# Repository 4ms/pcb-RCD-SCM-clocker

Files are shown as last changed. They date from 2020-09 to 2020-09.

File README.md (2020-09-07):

# PCB for RCD and SCM eurorack modules #

## Rotating Clock Divider, and Shuffling Clock Multiplier ##

### Pre-built versions (PCB v1.2) and Kit version (PCB v1.0.x) ###

This repository is an archive for the kit and pre-built versions of the RCD and SCM.

While we believe these files are accurate, there may be minor variations and/or corrections made during assembly that aren't recorded in these files.

Copyright (c) 2010, 2011, 2014, 2020 Dan Green (danngreen1@gmail.com)

Licensed by the [CC BY-NC-SA license](https://creativecommons.org/licenses/by-nc-sa/4.0/) (Creative Commons, Attribution, NonCommercial, ShareAlike).

Please read the above license carefully and contact us if you have any questions regarding acceptable use of these files.

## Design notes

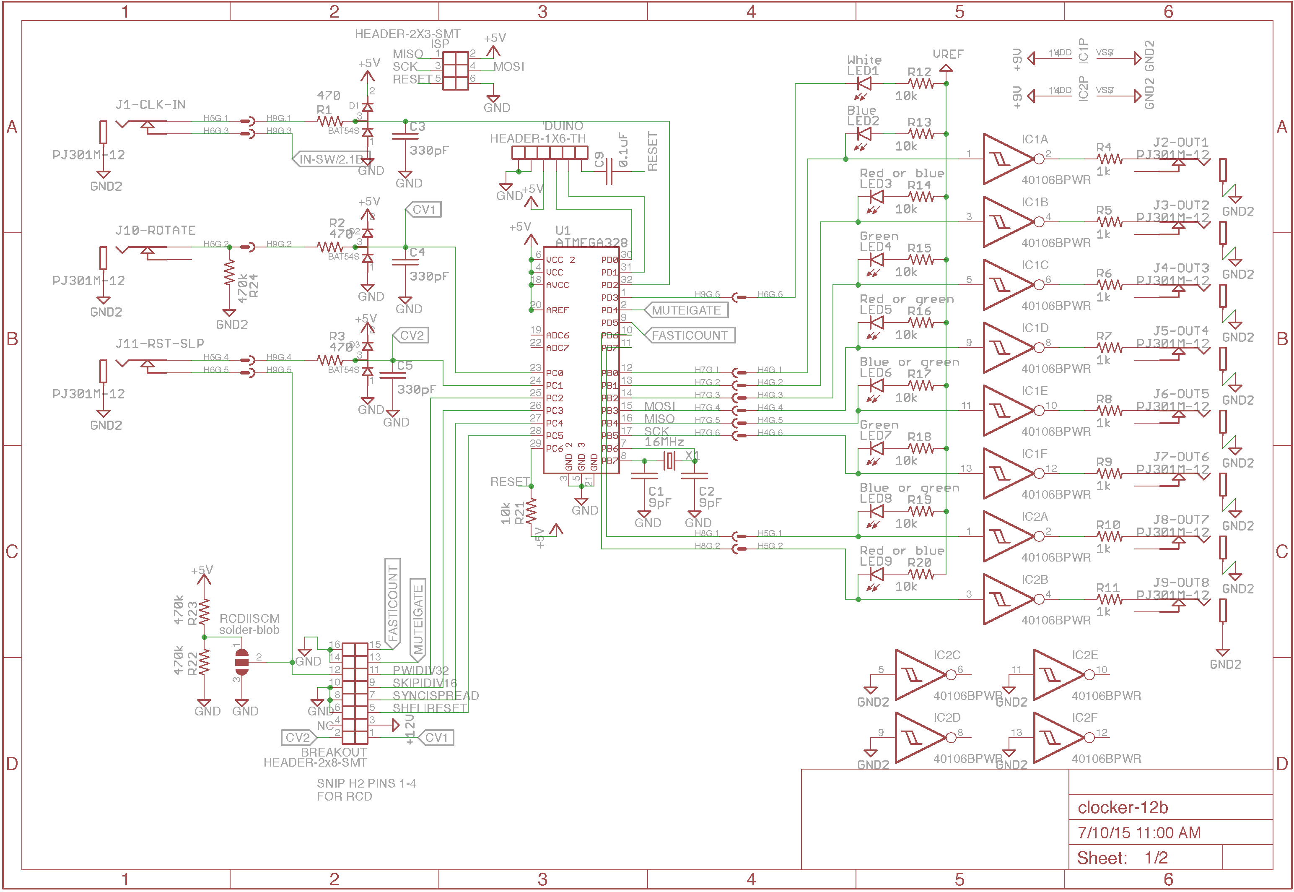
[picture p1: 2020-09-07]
pcb-v1.2/clocker-schematic-1.png

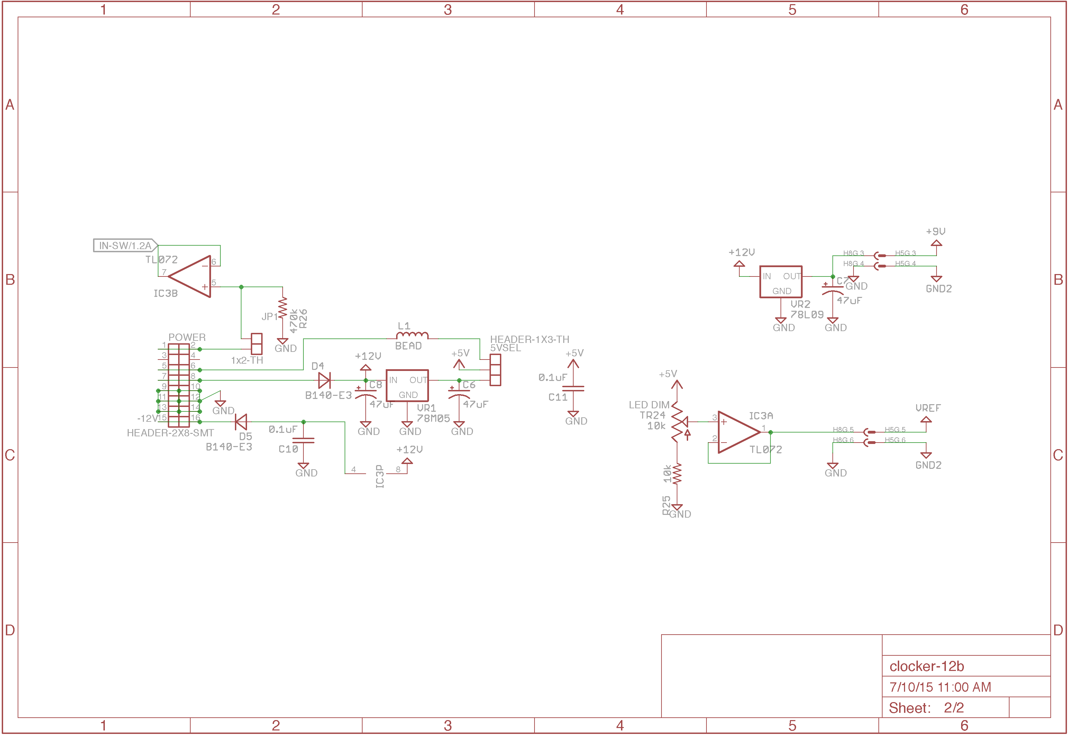
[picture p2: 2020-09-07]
pcb-v1.2/clocker-schematic-2.png

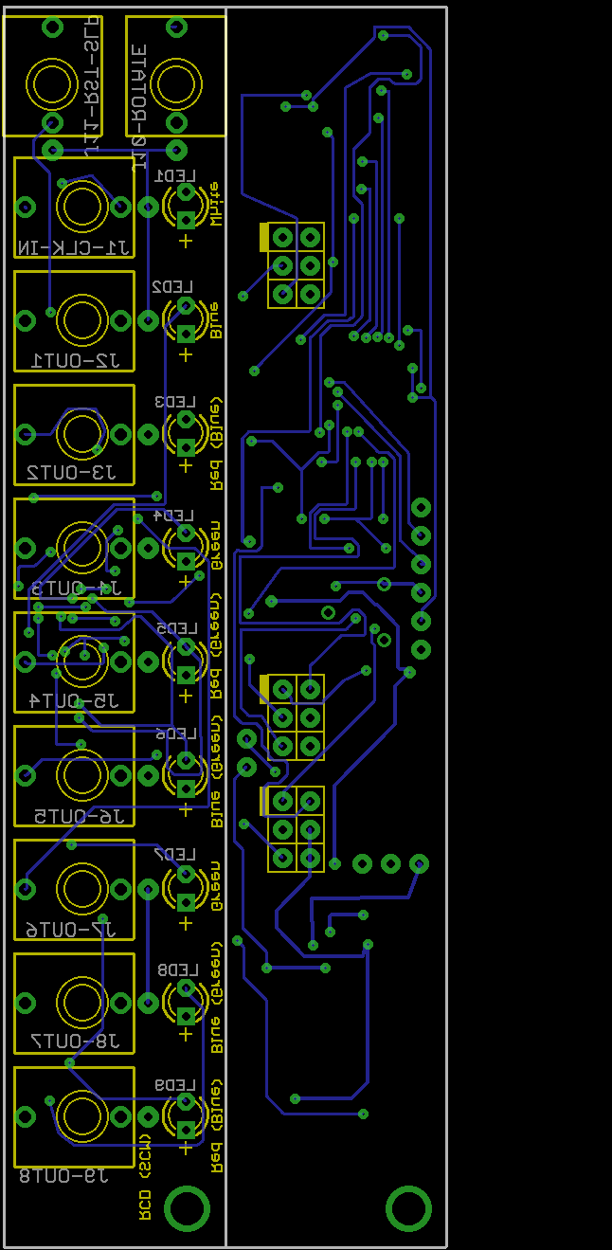
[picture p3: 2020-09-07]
pcb-v1.2/clocker-bottom.png

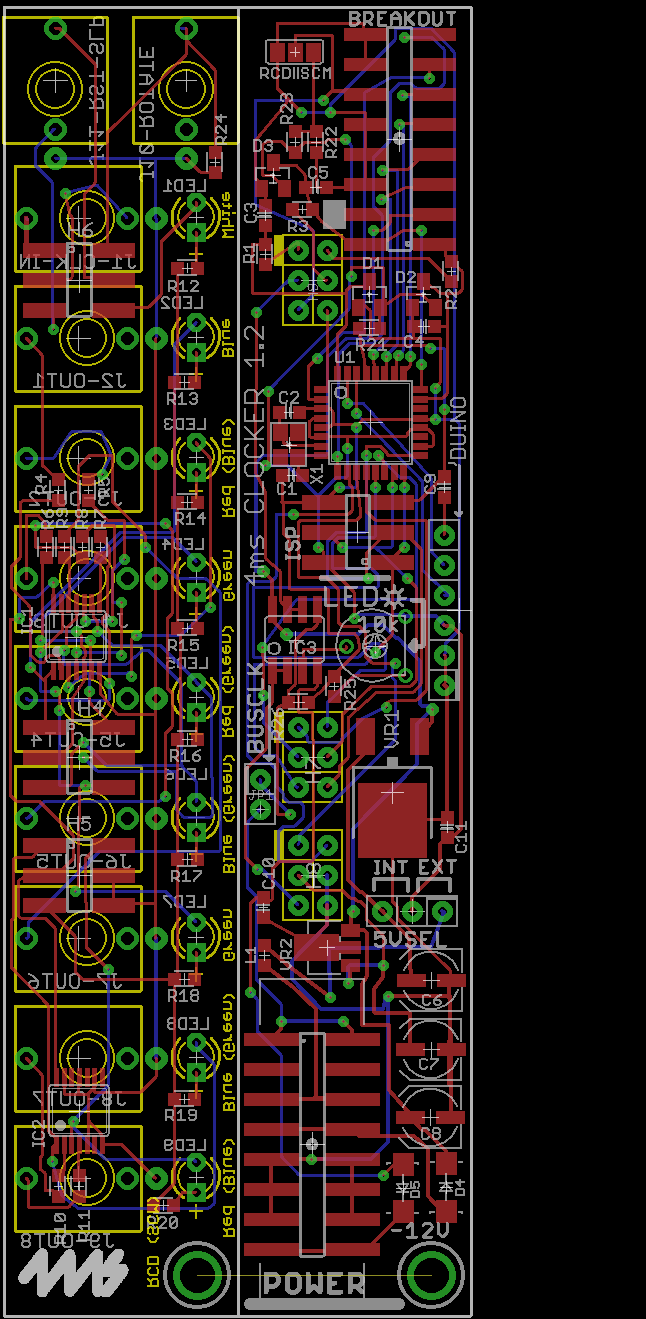
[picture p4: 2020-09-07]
pcb-v1.2/clocker-both.png

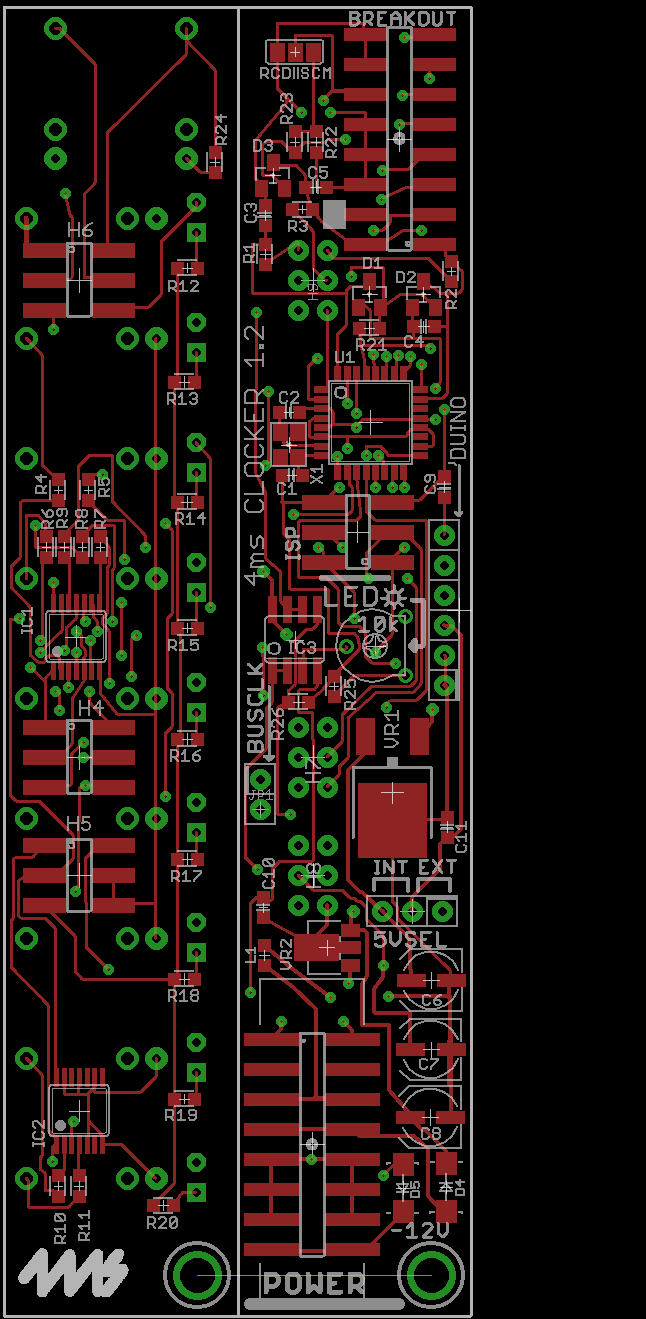
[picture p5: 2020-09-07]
pcb-v1.2/clocker-top.png

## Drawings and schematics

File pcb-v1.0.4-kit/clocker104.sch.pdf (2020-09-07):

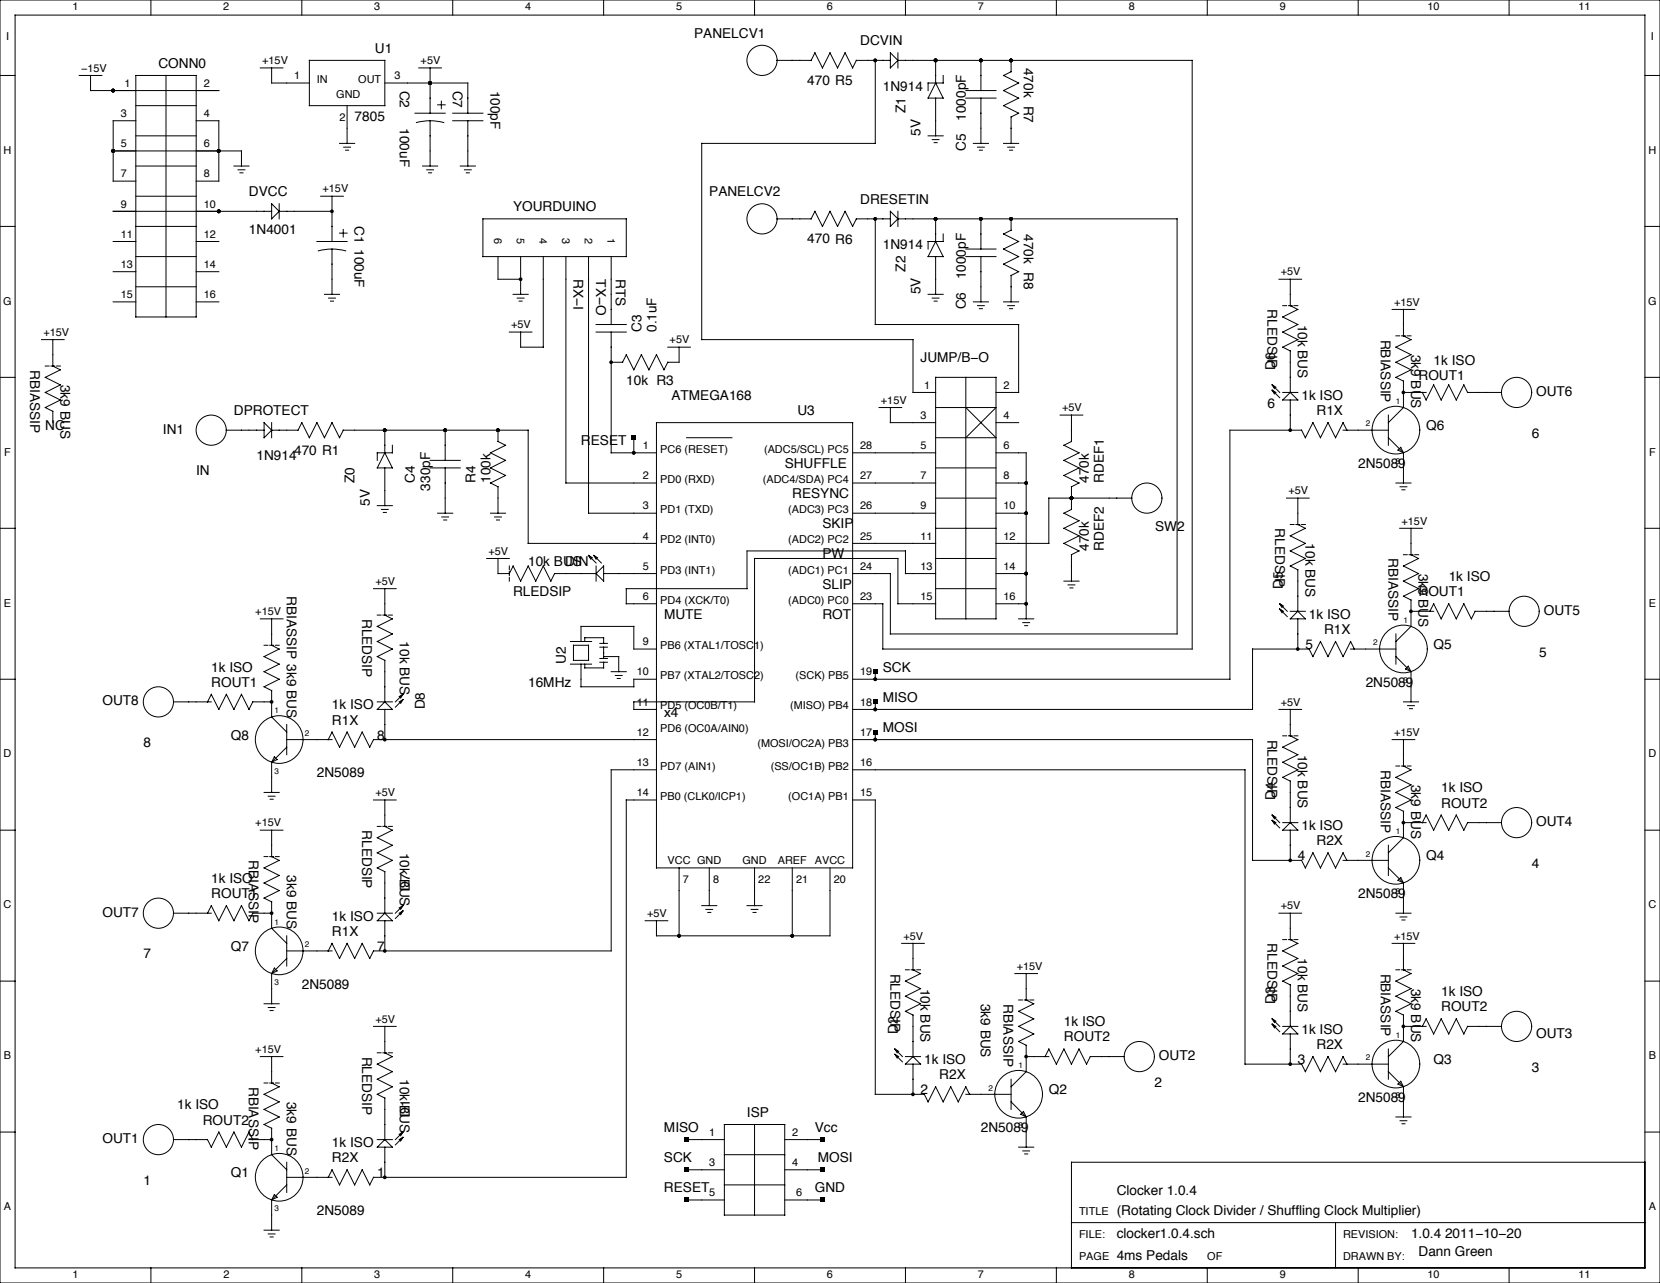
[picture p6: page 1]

Clocker 1.0.4
(Rotating Clock Divider / Shuffling Clock Multiplier)
clocker1.0.4.sch

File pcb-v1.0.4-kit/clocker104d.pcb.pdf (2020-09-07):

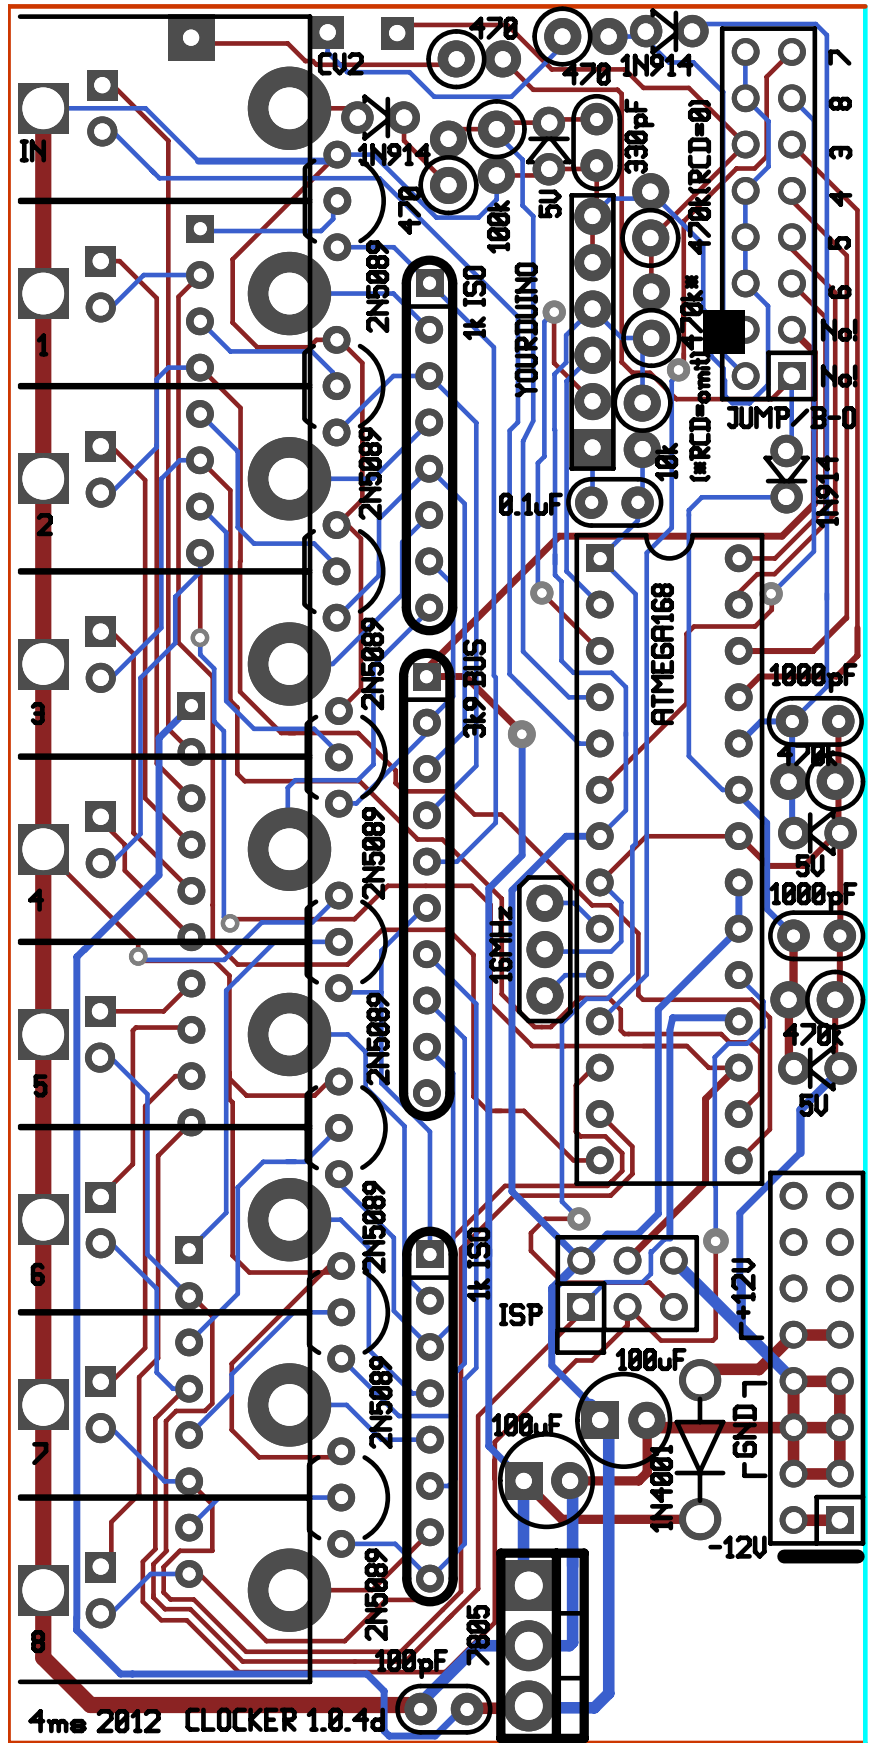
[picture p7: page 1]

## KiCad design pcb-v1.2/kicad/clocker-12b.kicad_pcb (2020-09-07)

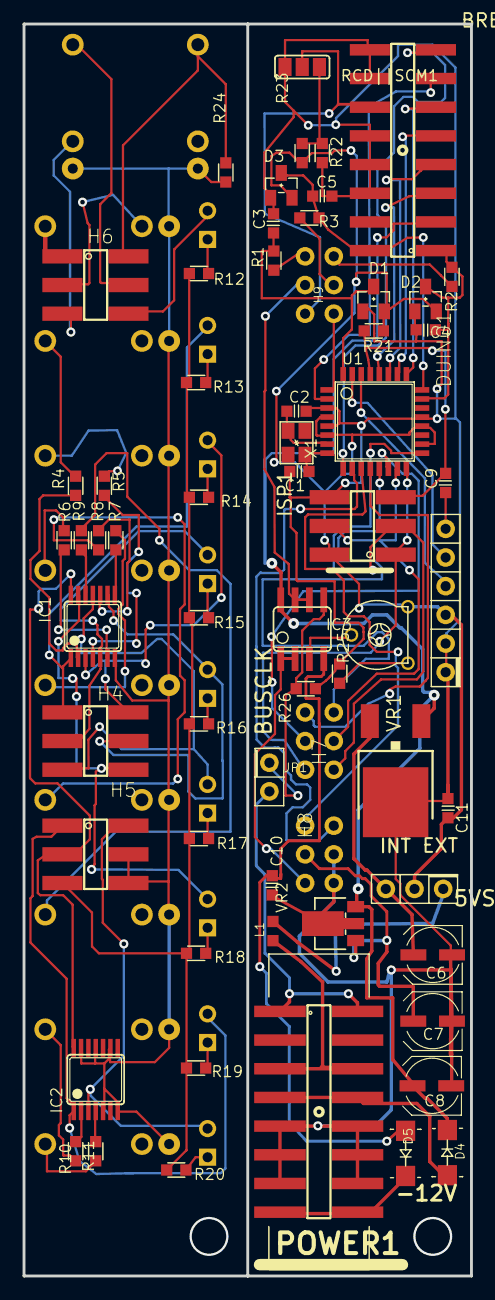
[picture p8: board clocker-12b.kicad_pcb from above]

Board: 16 copper layers, 39.6 x 110.9 mm, 84 parts (0 on the bottom side), 87 nets.

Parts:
5VSEL1: HEADER-1X3-TH
'DUINO1: HEADER-1X6-TH
BREAKOUT1: HEADER-2x8-SMT; HEADER-2X8-SMT
C1, C2: 9pF; C0603
C3, C4, C5: 330pF; C0603
C6, C7, C8: 47uF; C-POL-5
C9, C10, C11: 0.1uF; C0603
D1, D2, D3: BAT54S; SOT23
D4, D5: B140-E3; SMA
H4, H5, H6: HEADER-2X3-B2B-MALESMT; HEADER-2X3-SMT
H7, H8, H9: HEADER-2X3-B2B-FEMALETH-BOT; HEADER-2X3-TH-BOTTOM
IC1, IC2: 40106BPWR; TSSOP14
IC3: TL072; SOIC8
ISP1: HEADER-2X3-SMT
J1-CLK-IN1, J2-OUT1, J3-OUT2, J4-OUT3, J5-OUT4, J6-OUT5, J7-OUT6, J8-OUT7, J9-OUT8, J10-ROTATE1, J11-RST-SLP1: PJ301M-12
JP1: 1x2-TH; HEADER-1X2-TH
L1: BEAD; 0603
LED1: White; LED-T1
LED2: Blue; LED-T1
LED3, LED9: Red or blue; LED-T1
LED4, LED7: Green; LED-T1
LED5: Red or green; LED-T1
LED6, LED8: Blue or green; LED-T1
POWER1: HEADER-2X8-SMT; HEADER-2X8-SMT-SHROUDED
R1, R2, R3: 470; R0603
R4, R5, R6, R7, R8, R9, R10, R11: 1k; R0603
R12, R13, R14, R15, R16, R17, R18, R19, R20, R21, R25: 10k; R0603
R22, R23, R24, R26: 470k; R0603
RCD||SCM1: solder-blob; SJ_2
TR24: 10k; PIHER-6MM
U1: ATMEGA328; TQFP-32
VR1: 78M05; DPAK
VR2: 78L09; SOT89
X1: 16MHz; FA-238

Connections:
+5V: 5VSEL1.P$2, 'DUINO1.P$3, C11.2, D1.2, D2.2, D3.2, ISP1.2, R21.1, R23.2, TR24.3, U1.4, U1.6, U1.18, U1.20
+9V: H5.3, IC1.14, IC2.14
+12V: BREAKOUT1.3, C8.+, D4.K, IC3.8, VR1.1, VR2.3
+VREF: H5.5, R12.2, R13.2, R14.2, R15.2, R16.2, R17.2, R18.2, R19.2, R20.2
/clocker-12b_1/CV1: BREAKOUT1.1, C4.1, D2.3, R2.2, U1.23
/clocker-12b_1/CV2: BREAKOUT1.2, C5.1, D3.3, R3.2, U1.24
/clocker-12b_1/FAST|COUNT: BREAKOUT1.15, U1.9
/clocker-12b_1/MISO: H7.P$5, ISP1.1, U1.16
/clocker-12b_1/MOSI: H7.P$4, ISP1.4, U1.15
/clocker-12b_1/MUTE|GATE: BREAKOUT1.13, U1.2
/clocker-12b_1/PW|DIV32: BREAKOUT1.11, U1.25
/clocker-12b_1/RESET: C9.2, ISP1.5, R21.2, U1.29
/clocker-12b_1/SCK: H7.P$6, ISP1.3, U1.17
/clocker-12b_1/SHFL|RESET: BREAKOUT1.5, U1.28
/clocker-12b_1/SKIP|DIV16: BREAKOUT1.9, U1.26
/clocker-12b_1/SYNC|SPREAD: BREAKOUT1.7, U1.27
/clocker-12b_2/-12V: D5.K, POWER1.15, POWER1.16
AGND: H5.4, H5.6, IC1.7, IC2.5, IC2.7, IC2.9, IC2.11, IC2.13, J1-CLK-IN1.2, J2-OUT1.2, J3-OUT2.2, J4-OUT3.2, J5-OUT4.2, J6-OUT5.2, J7-OUT6.2, J8-OUT7.2, J9-OUT8.2, J10-ROTATE1.2, J11-RST-SLP1.2, R24.2
GND: 'DUINO1.P$1, 'DUINO1.P$2, BREAKOUT1.6, BREAKOUT1.8, BREAKOUT1.10, BREAKOUT1.14, BREAKOUT1.16, C1.2, C2.2, C3.2, C4.2, C5.2, C6.-, C7.-, C8.-, C10.1, C11.1, D1.1, D2.1, D3.1, H8.P$4, H8.P$6, ISP1.6, POWER1.9, POWER1.10, POWER1.11, POWER1.12, POWER1.13, POWER1.14, R22.1, R25.2, R26.2, RCD||SCM1.3, U1.3, U1.5, U1.21, VR1.4, VR2.2A, VR2.2B
IN-SW: H9.P$3, IC3.6, IC3.7
unnamed: 5VSEL1.P$1, L1.2
unnamed: 5VSEL1.P$3, C6.+, VR1.3
unnamed: 'DUINO1.P$4, U1.30
unnamed: 'DUINO1.P$5, U1.31
unnamed: 'DUINO1.P$6, C9.1
unnamed: BREAKOUT1.12, H9.P$5, RCD||SCM1.2
unnamed: C1.1, U1.8, X1.3
unnamed: C2.1, U1.7, X1.1
unnamed: C3.1, D1.3, R1.2, U1.32
unnamed: C7.+, H8.P$3, VR2.1
unnamed: C10.2, D5.A, IC3.4
unnamed: D4.A, POWER1.7, POWER1.8
unnamed: H4.1, IC1.1, LED2.K
unnamed: H4.2, IC1.3, LED3.K
unnamed: H4.3, IC1.5, LED4.K
unnamed: H4.4, IC1.9, LED5.K
unnamed: H4.5, IC1.11, LED6.K
unnamed: H4.6, IC1.13, LED7.K
unnamed: H5.1, IC2.1, LED8.K
unnamed: H5.2, IC2.3, LED9.K
unnamed: H6.1, J1-CLK-IN1.1
unnamed: H6.2, J10-ROTATE1.1, R24.1
unnamed: H6.3, J1-CLK-IN1.3
unnamed: H6.4, J11-RST-SLP1.1
unnamed: H6.5, J11-RST-SLP1.3
unnamed: H6.6, LED1.K
unnamed: H7.P$1, U1.12
unnamed: H7.P$2, U1.13
unnamed: H7.P$3, U1.14
unnamed: H8.P$1, U1.11
unnamed: H8.P$2, U1.10
unnamed: H8.P$5, IC3.1, IC3.2
unnamed: H9.P$1, R1.1
unnamed: H9.P$2, R2.1
unnamed: H9.P$4, R3.1
unnamed: H9.P$6, U1.1
unnamed: IC1.2, R4.1
unnamed: IC1.4, R5.1
unnamed: IC1.6, R6.1
unnamed: IC1.8, R7.1
unnamed: IC1.10, R8.1
unnamed: IC1.12, R9.1
unnamed: IC2.2, R10.1
unnamed: IC2.4, R11.1
unnamed: IC3.3, TR24.2
unnamed: IC3.5, JP1.P$1, R26.1
unnamed: J2-OUT1.1, R4.2
unnamed: J3-OUT2.1, R5.2
unnamed: J4-OUT3.1, R6.2
unnamed: J5-OUT4.1, R7.2
unnamed: J6-OUT5.1, R8.2
unnamed: J7-OUT6.1, R9.2
unnamed: J8-OUT7.1, R10.2
unnamed: J9-OUT8.1, R11.2
unnamed: JP1.P$2, POWER1.1, POWER1.2
unnamed: L1.1, POWER1.5, POWER1.6
unnamed: LED1.A, R12.1
unnamed: LED2.A, R13.1
unnamed: LED3.A, R14.1
unnamed: LED4.A, R15.1
unnamed: LED5.A, R16.1
unnamed: LED6.A, R17.1
unnamed: LED7.A, R18.1
unnamed: LED8.A, R19.1
unnamed: LED9.A, R20.1
unnamed: R22.2, R23.1, RCD||SCM1.1
unnamed: R25.1, TR24.1

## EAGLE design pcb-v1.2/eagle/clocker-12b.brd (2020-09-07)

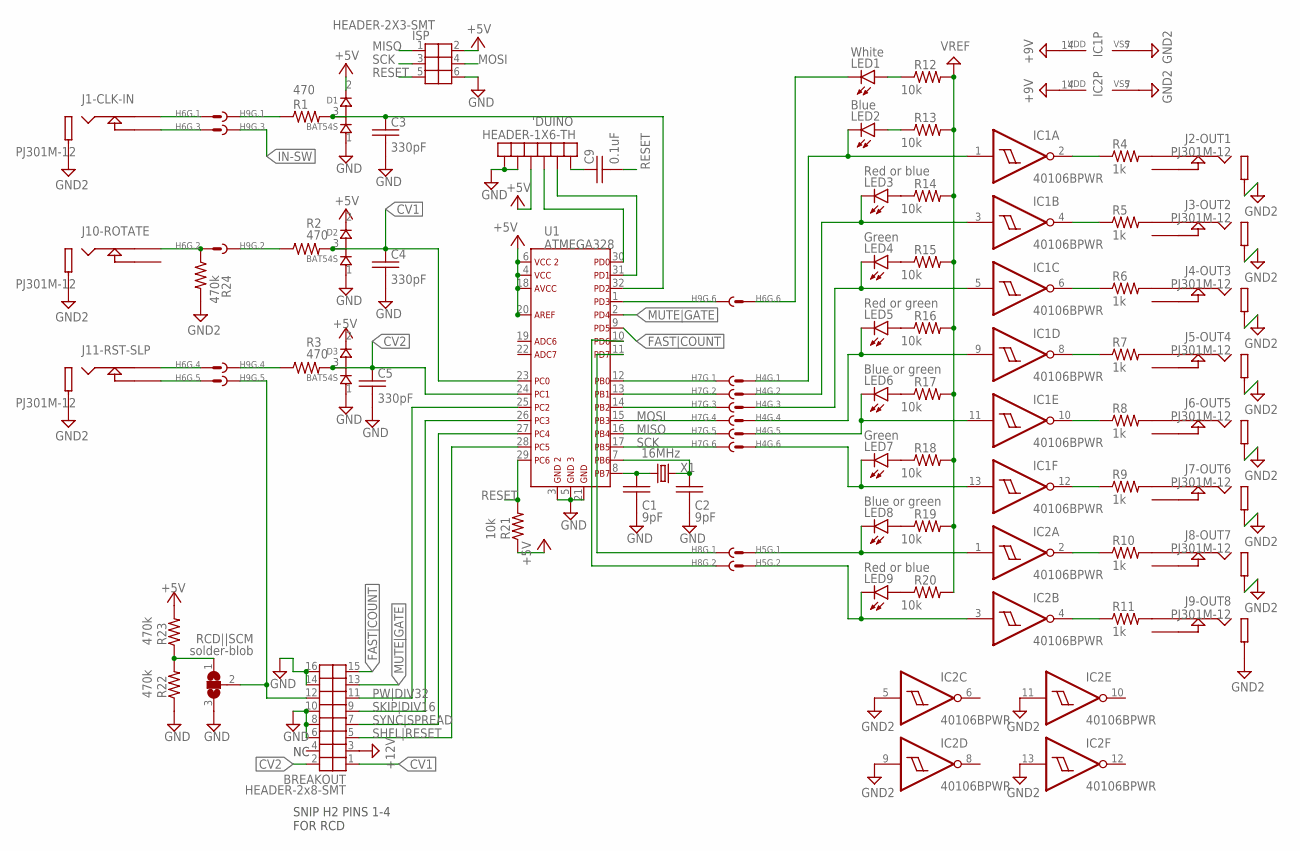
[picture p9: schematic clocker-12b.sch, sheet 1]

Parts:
'DUINO: HEADER-1X6-TH
BREAKOUT: HEADER-2x8-SMT; HEADER-2X8-SMT
C1, C2: 9pF; C0603
C3, C4, C5: 330pF; C0603
C9: 0.1uF; C0603
D1, D2, D3: BAT54S; SOT23
H4, H5, H6: HEADER-2X3-B2B-MALESMT; HEADER-2X3-SMT
H7, H8, H9: HEADER-2X3-B2B-FEMALETH-BOT; HEADER-2X3-TH-BOTTOM
IC1, IC2: 40106BPWR; TSSOP14
ISP: HEADER-2X3-SMT
J1-CLK-IN, J2-OUT1, J3-OUT2, J4-OUT3, J5-OUT4, J6-OUT5, J7-OUT6, J8-OUT7, J9-OUT8, J10-ROTATE, J11-RST-SLP: PJ301M-12
LED1: White; LED-T1
LED2: Blue; LED-T1
LED3, LED9: Red or blue; LED-T1
LED4, LED7: Green; LED-T1
LED5: Red or green; LED-T1
LED6, LED8: Blue or green; LED-T1
R1, R2, R3: 470; R0603
R4, R5, R6, R7, R8, R9, R10, R11: 1k; R0603
R12, R13, R14, R15, R16, R17, R18, R19, R20, R21: 10k; R0603
R22, R23, R24: 470k; R0603
RCD||SCM: solder-blob; SJ_2
U1: ATMEGA328; TQFP-32
X1: 16MHz; FA-238

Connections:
+5V: 'DUINO.P$3, D1.2 (CATHODE), D2.2 (CATHODE), D3.2 (CATHODE), ISP.2, R21.1, R23.2, U1.4, U1.6, U1.18, U1.20; also elsewhere on the board
+9V: IC1.14 (VDD), IC2.14 (VDD); also elsewhere on the board
+12V: BREAKOUT.3; also elsewhere on the board
+VREF: R12.2, R13.2, R14.2, R15.2, R16.2, R17.2, R18.2, R19.2, R20.2; also elsewhere on the board
AGND: IC1.7 (VSS), IC2.5 (I), IC2.7 (VSS), IC2.9 (I), IC2.11 (I), IC2.13 (I), J1-CLK-IN.2 (SLEEVE), J2-OUT1.2 (SLEEVE), J3-OUT2.2 (SLEEVE), J4-OUT3.2 (SLEEVE), J5-OUT4.2 (SLEEVE), J6-OUT5.2 (SLEEVE), J7-OUT6.2 (SLEEVE), J8-OUT7.2 (SLEEVE), J9-OUT8.2 (SLEEVE), J10-ROTATE.2 (SLEEVE), J11-RST-SLP.2 (SLEEVE), R24.2; also elsewhere on the board
CV1: BREAKOUT.1, C4.1, D2.3 (COMMON), R2.2, U1.23
CV2: BREAKOUT.2, C5.1, D3.3 (COMMON), R3.2, U1.24
CV2-SW: BREAKOUT.12, H9.P$5, RCD||SCM.2
FAST|COUNT: BREAKOUT.15, U1.9
GND: 'DUINO.P$1, 'DUINO.P$2, BREAKOUT.6, BREAKOUT.8, BREAKOUT.10, BREAKOUT.14, BREAKOUT.16, C1.2, C2.2, C3.2, C4.2, C5.2, D1.1 (ANODE), D2.1 (ANODE), D3.1 (ANODE), ISP.6, R22.1, RCD||SCM.3, U1.3, U1.5, U1.21; also elsewhere on the board
IN-SW: H9.P$3; also elsewhere on the board
INLED: H6.6, LED1.K (C)
MISO: H7.P$5, ISP.1, U1.16
MOSI: H7.P$4, ISP.4, U1.15
MUTE|GATE: BREAKOUT.13, U1.2
unnamed: C1.1, U1.8, X1.3 (2)
unnamed: C2.1, U1.7, X1.1
unnamed: J2-OUT1.1 (TIP), R4.2
unnamed: J3-OUT2.1 (TIP), R5.2
unnamed: J4-OUT3.1 (TIP), R6.2
unnamed: J5-OUT4.1 (TIP), R7.2
unnamed: J6-OUT5.1 (TIP), R8.2
unnamed: J7-OUT6.1 (TIP), R9.2
unnamed: J8-OUT7.1 (TIP), R10.2
unnamed: J9-OUT8.1 (TIP), R11.2
unnamed: C3.1, D1.3 (COMMON), R1.2, U1.32
unnamed: LED4.A, R15.1
unnamed: LED5.A, R16.1
unnamed: H6.1, J1-CLK-IN.1 (TIP)
unnamed: H9.P$4, R3.1
unnamed: H9.P$2, R2.1
unnamed: LED1.A, R12.1
unnamed: LED6.A, R17.1
unnamed: 'DUINO.P$4, U1.30
unnamed: LED2.A, R13.1
unnamed: LED3.A, R14.1
unnamed: LED7.A, R18.1
unnamed: LED8.A, R19.1
unnamed: LED9.A, R20.1
unnamed: R22.2, R23.1, RCD||SCM.1
unnamed: H8.P$1, U1.11
unnamed: H9.P$6, U1.1
unnamed: H8.P$2, U1.10
unnamed: H7.P$1, U1.12
unnamed: 'DUINO.P$5, U1.31
unnamed: 'DUINO.P$6, C9.1
unnamed: H6.3, J1-CLK-IN.3 (TIP-SW)
unnamed: H6.2, J10-ROTATE.1 (TIP), R24.1
unnamed: H6.4, J11-RST-SLP.1 (TIP)
unnamed: IC2.4 (O), R11.1
unnamed: IC1.2 (O), R4.1
unnamed: IC1.4 (O), R5.1
unnamed: IC1.6 (O), R6.1
unnamed: IC1.8 (O), R7.1
unnamed: IC1.10 (O), R8.1
unnamed: IC1.12 (O), R9.1
unnamed: IC2.2 (O), R10.1
unnamed: H6.5, J11-RST-SLP.3 (TIP-SW)
unnamed: H7.P$3, U1.14
unnamed: H7.P$2, U1.13
unnamed: H9.P$1, R1.1
OUTLINE1: H4.1, IC1.1 (I), LED2.K (C)
OUTLINE2: H4.2, IC1.3 (I), LED3.K (C)
OUTLINE3: H4.3, IC1.5 (I), LED4.K (C)
OUTLINE4: H4.4, IC1.9 (I), LED5.K (C)
OUTLINE5: H4.5, IC1.11 (I), LED6.K (C)
OUTLINE6: H4.6, IC1.13 (I), LED7.K (C)
OUTLINE7: H5.1, IC2.1 (I), LED8.K (C)
OUTLINE8: H5.2, IC2.3 (I), LED9.K (C)
PW|DIV32: BREAKOUT.11, U1.25
RESET: C9.2, ISP.5, R21.2, U1.29
SCK: H7.P$6, ISP.3, U1.17
SHFL|RESET: BREAKOUT.5, U1.28
SKIP|DIV16: BREAKOUT.9, U1.26
SYNC|SPREAD: BREAKOUT.7, U1.27

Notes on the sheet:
SNIP H2 PINS 1-4 FOR RCD

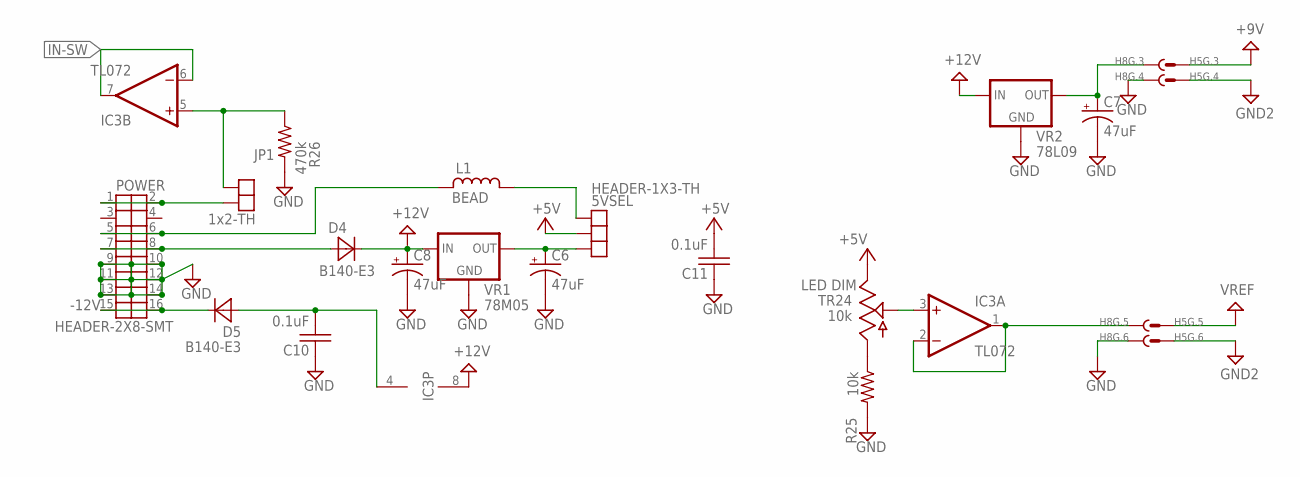
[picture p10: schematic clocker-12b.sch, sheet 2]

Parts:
5VSEL: HEADER-1X3-TH
C6, C7, C8: 47uF; C-POL-5
C10, C11: 0.1uF; C0603
D4, D5: B140-E3; SMA
H5: HEADER-2X3-B2B-MALESMT; HEADER-2X3-SMT
H8: HEADER-2X3-B2B-FEMALETH-BOT; HEADER-2X3-TH-BOTTOM
IC3: TL072; SOIC8
JP1: 1x2-TH; HEADER-1X2-TH
L1: BEAD; 0603
POWER: HEADER-2X8-SMT; HEADER-2X8-SMT-SHROUDED
R25: 10k; R0603
R26: 470k; R0603
TR24: 10k; PIHER-6MM
VR1: 78M05; DPAK
VR2: 78L09; SOT89

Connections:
+5V: 5VSEL.P$2, C11.2, TR24.3; also elsewhere on the board
+9V: H5.3; also elsewhere on the board
+12V: C8.+, D4.K (C), IC3.8 (V+), VR1.1 (IN), VR2.3 (IN); also elsewhere on the board
+VREF: H5.5; also elsewhere on the board
-12V: D5.K (C), POWER.15, POWER.16
AGND: H5.4, H5.6; also elsewhere on the board
GND: C6.-, C7.-, C8.-, C10.1, C11.1, H8.P$4, H8.P$6, POWER.9, POWER.10, POWER.11, POWER.12, POWER.13, POWER.14, R25.2, R26.2, VR1.4 (GND), VR2.2A (GND), VR2.2B (GND); also elsewhere on the board
IN-SW: IC3.6 (-IN), IC3.7 (OUT); also elsewhere on the board
unnamed: IC3.5 (+IN), JP1.P$1, R26.1
unnamed: C10.2, D5.A, IC3.4 (V-)
unnamed: JP1.P$2, POWER.1, POWER.2
unnamed: L1.1, POWER.5, POWER.6
unnamed: D4.A, POWER.7, POWER.8
unnamed: C7.+, H8.P$3, VR2.1 (OUT)
unnamed: 5VSEL.P$3, C6.+, VR1.3 (OUT)
unnamed: 5VSEL.P$1, L1.2 (4)
unnamed: H8.P$5, IC3.1 (OUT), IC3.2 (-IN)
unnamed: IC3.3 (+IN), TR24.2
unnamed: R25.1, TR24.1

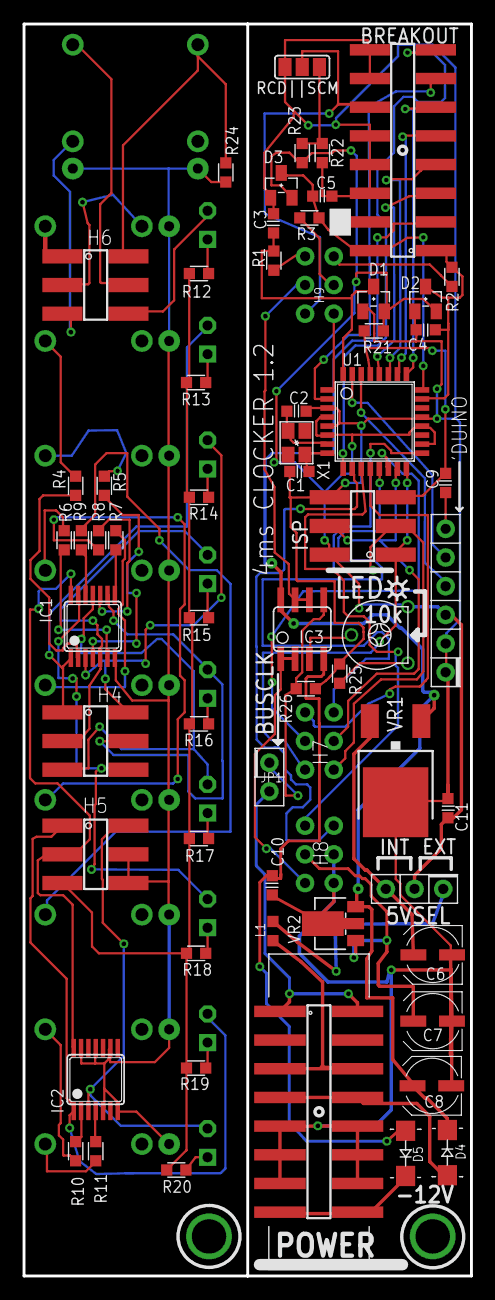
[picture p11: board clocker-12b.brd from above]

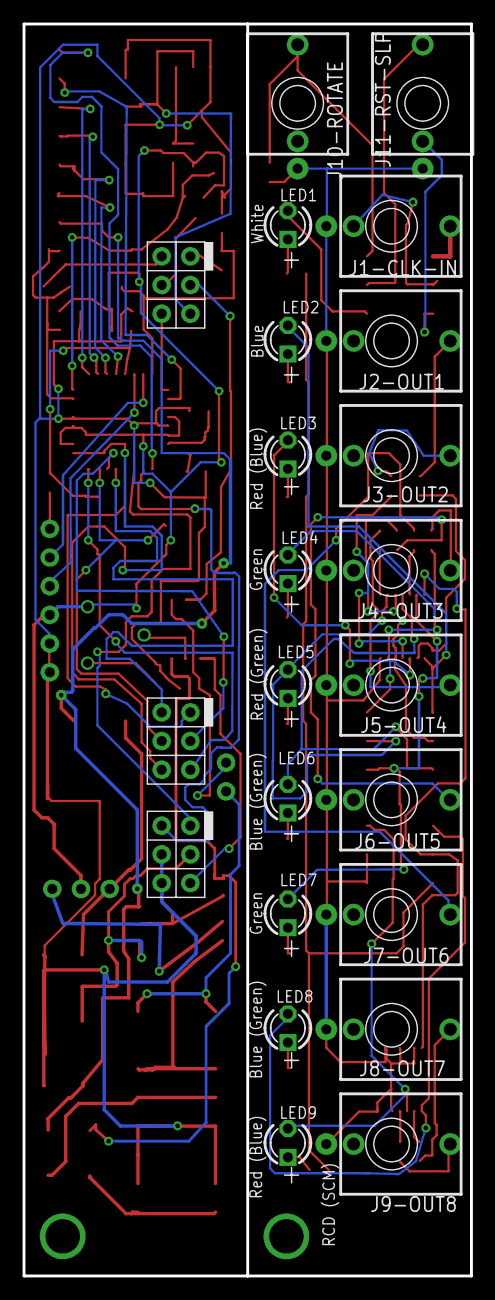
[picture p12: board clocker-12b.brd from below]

Board: 2 copper layers, 39.6 x 110.9 mm, 84 parts (20 on the bottom side), 87 nets.
